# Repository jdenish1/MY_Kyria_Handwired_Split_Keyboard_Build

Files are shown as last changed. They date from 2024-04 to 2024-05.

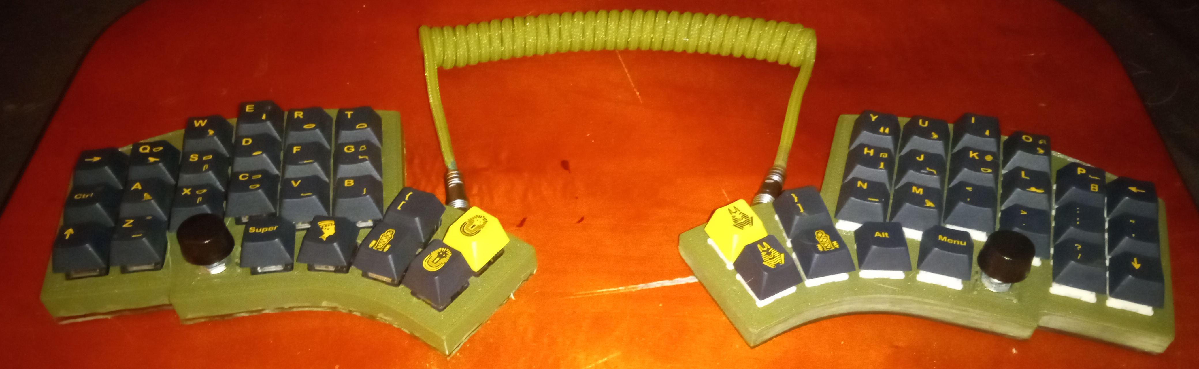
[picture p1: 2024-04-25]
Pics/2 - Completed Kyria Build 2.jpg

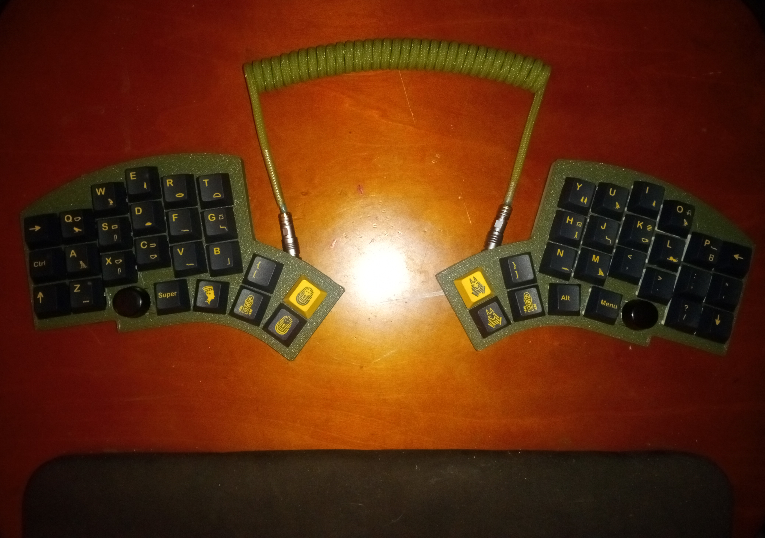
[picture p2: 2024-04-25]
Pics/1 - Completed Kyria Build 1.jpg

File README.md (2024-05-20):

<h1 align="center">Kyria_Handwired Split Keyboard</h1>

<div align="center">
<br />


<details open="open">
<summary>Table of Contents</summary>

- [About](#about)
  - [Bill of Materials](#built-with)
- [Getting Started](#getting-started)
  - [Prerequisites](#prerequisites)
  - [Usage](#usage)
    - [Cookiecutter template](#cookiecutter-template)
    - [Manual setup](#manual-setup)
    - [Variables reference](#variables-reference)
- [Roadmap](#roadmap)
- [Contributing](#contributing)
- [Support](#support)
- [License](#license)
- [Acknowledgements](#acknowledgements)

</details>

---

## About

<table>
<tr>
<td>

This is my rendition of a handwired split keyboard I did based on the Kyria by Thomas Baard ---> https://blog.splitkb.com/introducing-the-kyria/

This is my first split KB attempt and have been wanting to build a split for a while now. Ive done two other keyboard builds prior. Not only did I get inspiration from the original creator Thomas Baard but also from another github member MoltenZaz linked here ---> https://github.com/MoltenZaz/Handwired-Kyria. I dont know these guys personally but I got inspiration from their builds.

Try out the Keyswitch spacing with Baards printout here ----> https://docs.splitkb.com/hc/en-us/articles/360010627159-Can-I-try-the-Kyria-before-I-buy?ref=blog.splitkb.com

I added 2 EC11 rotary encoders, one per side, for the bottom left key on left side and bottom right key of right side which added a bit of complexity to the firmware build.

I also added WS2812 RGB Underglow to each side and ditched the 3d printed bottom plate for a handmade clear acrylic bottom plate.

Anyways, just made this public in case it helps anyone else out, in the spirit of the open source movement....

</td>
</tr>
</table>

### BOM
| # | Part | Type | Qty | Cost |
|:-:|:---:|:---|:----:|:---:|
| 1a| Keyswitches | Glorious Panda Tactile Switches - Unlubed |  x25 | $24.99 |
| 1b| Keyswitches | Cherry Red Tactile Switches - Unlubed |  x25 | $14.63 |
| 2 | Diodes | 1N4148 THT High Speed Switching Diodes | x100 | $ 2.30 |
| 3 | Controllers | Waveshare RP2040-Zero Microcontrollers | x2 | $ 4.08 |
| 4 | Encoders | EC11 20Pos 5VDC 7 Pin 360* Encoder w knobs| x2 | $ 4.03 |
| 5 | Connectors  | XS6 Mini Aviation Plug and Socket - 4Pin  | x2 | $ 8.16 |
| 6 | Heat Inserts| M2x6mm Heat Set Inserts - x30 needed | x50  | $ 4.68 |
| 7 | Screws | M2x6mm Countersunk - Black - x30 needed | x50  | $ 3.04 |
| 8 | Keycaps | GMK Pharoah Black & Gold Full Set | x1 | $24.99 |
| 9 | Keyboard Feet| Screw-In or Tape-On Your Choice | x10  | $ 4.99 |
| 10| 3D Printed Case | Printed on my Ratrig V Core 3 - On Hand| 4 pc | $ 0.00 |
| 11| Wire | I used Cat5e Solid Wire 26awg - On Hand | x1 | $ 1.00 |
| 12| USB Cable Wire| 24/4 shielded cable - On Hand ($0.45/ft |1-5ft | $ 1.50 |

## Getting Started

### Prerequisites

Download [QMK_MSYS](https://github.com/qmk/qmk_distro_msys/releases/download/1.9.0/QMK_MSYS.exe)
-or- If you use WSL - Windows Subsidiary for Linux - Download [QMK_WSL](https://github.com/qmk/qmk_distro_wsl/releases/download/0.4.2/QMK_WSL.exe)

Go to [qmk_firmware](https://github.com/qmk/qmk_firmware) and Fork your own repo 
[MY Repo](https://github.com/jdenish1/qmk_firmware)

Install QMK_WSL and run
```sh
qmk-admin
```
and complete quickstart wizard using your fork of qmk_firmware.

### Usage

Run
```sh
qmk compile -kb <keyboard/location> -km <keymap/location>
```




#### Manual setup

Please follow these steps for manual setup:

1. [Download the precompiled template](https://github.com/dec0dOS/amazing-github-template/releases/download/latest/template.zip)
2. Replace all the [variables](#variables-reference) to your desired values
3. Initialize the repo in the precompiled template folder

    `or`

    Move the necessary files from precompiled template folder to your existing project directory. Don't forget the `.github` directory that may be hidden by default in your operating system

## Roadmap

See the [open issues](https://github.com/dec0dOS/amazing-github-template/issues) for a list of proposed features (and known issues).

- [Top Feature Requests](https://github.com/dec0dOS/amazing-github-template/issues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) (Add your votes using the 👍 reaction)
- [Top Bugs](https://github.com/dec0dOS/amazing-github-template/issues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) (Add your votes using the 👍 reaction)
- [Newest Bugs](https://github.com/dec0dOS/amazing-github-template/issues?q=is%3Aopen+is%3Aissue+label%3Abug)

## Contributing

First off, thanks for taking the time to contribute! Contributions are what makes the open-source community such an amazing place to learn, inspire, and create. Any contributions you make will benefit everybody else and are **greatly appreciated**.

Please try to create bug reports that are:

- _Reproducible._ Include steps to reproduce the problem.
- _Specific._ Include as much detail as possible: which version, what environment, etc.
- _Unique._ Do not duplicate existing opened issues.
- _Scoped to a Single Bug._ One bug per report.

Please adhere to this project's [code of conduct](docs/CODE_OF_CONDUCT.md).

You can use [markdownlint-cli](https://github.com/igorshubovych/markdownlint-cli) to check for common markdown style inconsistency.

## Support

## Acknowledgements

Thanks for these awesome resources that were used during the development of the **Amazing GitHub template**:

- <https://github.com/cookiecutter/cookiecutter>
- <https://github.github.com/gfm/>
- <https://tom.preston-werner.com/2010/08/23/readme-driven-development.html>
- <https://changelog.com/posts/top-ten-reasons-why-i-wont-use-your-open-source-project>
- <https://thoughtbot.com/blog/how-to-write-a-great-readme>
- <https://www.makeareadme.com>

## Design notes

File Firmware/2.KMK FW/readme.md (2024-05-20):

Was having a hard time getting QMK to compile so I decided to try KMK FW instead. Before completely getting this working i started fresh with QMK and got it compiled on the default keymap. QMK FW files are more current and up to date so check that folder for current FW Files as well as the .uf2 and .hex files for flashing.

Thanks

Peace

-JRad

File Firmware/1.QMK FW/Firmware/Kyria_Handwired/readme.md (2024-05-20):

# kyria_handwired

kyria_handwired

*A short description of the keyboard/project*

* Keyboard Maintainer: [jdenish1](https://github.com/jdenish1)
* Hardware Supported: *The PCBs, controllers supported*
* Hardware Availability: *Links to where you can find this hardware*

Make example for this keyboard (after setting up your build environment):

    make kyria_handwired:default

Flashing example for this keyboard:

    make kyria_handwired:default:flash

See the [build environment setup](https://docs.qmk.fm/#/getting_started_build_tools) and the [make instructions](https://docs.qmk.fm/#/getting_started_make_guide) for more information. Brand new to QMK? Start with our [Complete Newbs Guide](https://docs.qmk.fm/#/newbs).

## Bootloader

Enter the bootloader in 3 ways:

* **Bootmagic reset**: Hold down the key at (0,0) in the matrix (usually the top left key or Escape) and plug in the keyboard
* **Physical reset button**: Briefly press the button on the back of the PCB - some may have pads you must short instead
* **Keycode in layout**: Press the key mapped to `QK_BOOT` if it is available

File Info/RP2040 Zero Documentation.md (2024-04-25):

# RP2040-Zero by Waveshare

<picture>
 <source media="(prefers-color-scheme: dark)" srcset="https://www.waveshare.com/img/devkit/RP2040-Zero/RP2040-Zero-details-1.jpg">
 <source media="(prefers-color-scheme: light)" srcset="https://www.waveshare.com/img/devkit/RP2040-Zero/RP2040-Zero-details-1.jpg">
 Waveshare RP2040-Zero Microcontroller Image
</picture>

## A Pico-like MCU board based on Raspberry Pi RP2040

### Board specifications

* RP2040 microcontroller chip designed by Raspberry Pi in the United Kingdom

* Dual-core Arm Cortex M0+ processor, flexible clock running up to 133 MHz

* 264KB of SRAM, and 2MB of on-board Flash memory

* USB-C connector, keeps it up to date, easier to use

* Castellated module allows soldering direct to carrier boards

* USB 1.1 with device and host support

* Low-power sleep and dormant modes

* Drag-and-drop programming using mass storage over USB

* 29 × multi-function GPIO pins (20× via edge pinout, others via solder points)

* 2 × SPI, 2 × I2C, 2 × UART, 4 × 12-bit ADC, 16 × controllable PWM channels

* Accurate clock and timer on-chip

* Temperature sensor

* Accelerated floating-point libraries on-chip

* 8 × Programmable I/O (PIO) state machines for custom peripheral support

#### Purchase

  [Waveshare](https://www.waveshare.com/rp2040-zero.htm)

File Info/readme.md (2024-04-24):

# Kyria's Default Keymap

KLE render of the default Kyria keymap with QWERTY as the base layer. Layers are shown in sublegends.

The default keymap contains 5 layers which allows it to include all keys found on an ANSI layout TKL keyboard plus media keys.
Hardware features of the Kyria such as OLEDs, rotary encoders and underglow are also supported.

The five different layers are the following:
1. Base layer (QWERTY, Colemak-DH or Dvorak)
2. Navigation layer
3. Symbols/Numbers layer
4. Function layer
5. Adjust layer

## Base layer(s)
```
Base Layer: -

,-------------------------------------------.                              ,-------------------------------------------.
|  Tab   |   -  |   -  |   -  |   -  |   -  |                              |   -  |   -  |   -  |   -  |   -  |  Bksp  |
|--------+------+------+------+------+------|                              |------+------+------+------+------+--------|
|Ctrl/Esc|   -  |   -  |   -  |   -  |   -  |                              |   -  |   -  |   -  |   -  |   -  |Ctrl/ - |
|--------+------+------+------+------+------+-------------.  ,-------------+------+------+------+------+------+--------|
| LShift |   -  |   -  |   -  |   -  |   -  | [ {  |CapsLk|  |F-Keys|  ] } |   -  |   -  |   -  |   -  |   -  | RShift |
`----------------------+------+------+------+------+------|  |------+------+------+------+------+----------------------'
                       |Adjust| LGUI | LAlt/| Space| Nav  |  | Sym  | Space| AltGr| RGUI | Menu |
                       |      |      | Enter|      |      |  |      |      |      |      |      |
                       `----------------------------------'  `----------------------------------'
```
Three different well-known keyboard layouts are provided to fill in the placeholder `-` keys: QWERTY, Colemak-DH, and Dvorak. The default layer can be changed at runtime, more info on that in the section on the [adjust layer](#adjust-layer).

For the rest of this write-up, the base layer will be assumed to be QWERTY and will be used as a reference to describe physical keys, e.g. “<kbd>B</kbd> key” vs, the much more verbose, “lower inner index key”.

```
Base Layer: QWERTY

,-------------------------------------------.                              ,-------------------------------------------.
|  Tab   |   Q  |   W  |   E  |   R  |   T  |                              |   Y  |   U  |   I  |   O  |   P  |  Bksp  |
|--------+------+------+------+------+------|                              |------+------+------+------+------+--------|
|Ctrl/Esc|   A  |   S  |   D  |   F  |   G  |                              |   H  |   J  |   K  |   L  | ;  : |Ctrl/' "|
|--------+------+------+------+------+------+-------------.  ,-------------+------+------+------+------+------+--------|
| LShift |   Z  |   X  |   C  |   V  |   B  | [ {  |CapsLk|  |F-keys|  ] } |   N  |   M  | ,  < | . >  | /  ? | RShift |
`----------------------+------+------+------+------+------|  |------+------+------+------+------+----------------------'
                       |Adjust| LGUI | LAlt/| Space| Nav  |  | Sym  | Space| AltGr| RGUI | Menu |
                       |      |      | Enter|      |      |  |      |      |      |      |      |
                       `----------------------------------'  `----------------------------------'
```

Aside from variations in the alpha cluster, the rest of the base keys remain the same and are designed to feel familiar.

Step-by-step animation of the transformation of an ortholinear TKL to a Kyria

<details>
After making transformations to the classic ANSI US QWERTY TKL 60% to arrive to the layout of the Kyria, as illustrated in the animation above, the result looks like this:

```
,-------------------------------------------.                              ,-------------------------------------------.
|  Tab   |   Q  |   W  |   E  |   R  |   T  |                              |   Y  |   U  |   I  |   O  |   P  |  Bksp  |
|--------+------+------+------+------+------|                              |------+------+------+------+------+--------|
| Cap Lk |   A  |   S  |   D  |   F  |   G  |                              |   H  |   J  |   K  |   L  | ;  : | '  "   |
|--------+------+------+------+------+------+-------------.  ,-------------+------+------+------+------+------+--------|
| LShift |   Z  |   X  |   C  |   V  |   B  |      |      |  |      |      |   N  |   M  | ,  < | . >  | /  ? | RShift |
`----------------------+------+------+------+------+------|  |------+------+------+------+------+----------------------'
                       | LCtrl| LGUI | LAlt | Space|      |  |      | Space| AltGr| RGUI | Menu |
                       |      |      |      |      |      |  |      |      |      |      |      |
                       `----------------------------------'  '----------------------------------'
```

First thing to notice is the presence of blank keys. To fill in the blank keys above the <kbd>Space</kbd> keys, we can take inspiration from other split keyboards featuring an extra inner index column on each half. A common mapping for those kind of keys are the bracket keys that got removed in the fourth step of the animated transformation. The thumb keys besides <kbd>Space</kbd>s is prime real estate for dedicated layer-switching keys. It doesn't matter on which side is assigned the sym-layer-switch key but it helps to keep the nav-layer-switch on the left in order to keep the arrow keys on the right side like on a classic keyboard, so we'll put nav on the left and sym on the right. We'll address the remaining blank thumb keys later.

The base layer is starting to form but there remains some flaws. One glaring issue is the position of Control. Control is a very commonly used function but the key on which it sits right now is way too tucked in under the hand to be able to press it comfortably with either the thumb or the pinky from resting position. In fact, installing a rotary encoder there is a common move among Kyria users and I guarantee you that activating Control by holding down a rotary encoder does not spark joy. Instead, let's employ a popular trick that involves remapping the current Caps Lock key, which is positioned at a comfortable position on the keyboard, to Control. 

We can go further though; a variant of this trick makes the Control key produce Escape when tapped. This is called a “modtap”. There is no use to tapping Control by itself without chording it with another key and there is no use to holding down the Esc key so why not combine the two into a single key?

All of this leaves us with three blank keys.

```
,-------------------------------------------.                              ,-------------------------------------------.
|  Tab   |   Q  |   W  |   E  |   R  |   T  |                              |   Y  |   U  |   I  |   O  |   P  |  Bksp  |
|--------+------+------+------+------+------|                              |------+------+------+------+------+--------|
|Ctrl/Esc|   A  |   S  |   D  |   F  |   G  |                              |   H  |   J  |   K  |   L  | ;  : | '  "   |
|--------+------+------+------+------+------+-------------.  ,-------------+------+------+------+------+------+--------|
| LShift |   Z  |   X  |   C  |   V  |   B  | [ {  |      |  |      |  ] } |   N  |   M  | ,  < | . >  | /  ? | RShift |
`--------+-------------+--------------------+------+------|  |------+------+--------------------+------+---------------'
                       |      | LGUI | LAlt | Space| Nav  |  | Sym  | Space| AltGr| RGUI | Menu |
                       |      |      |      |      |      |  |      |      |      |      |      |
                       `----------------------------------'  '----------------------------------'
```

These keys are not easily reachable while touch typing (that is, not reachable without picking up your hand) and should thus be associated with functions that you are not likely to be typed within a stream of text. The idea is that if you have to pick up your hand to hit a key, you want it to be at a time when you are likely to be pausing your interaction with the machine, rather than in the midst of a flurry of typing.  They're thus well suited for accessing the adjust layer and the function layer. We can also toss in Caps Lock even though it is an editing-type function that gets used within a stream of text because shouting in ALL-CAPS should be a deliberate action.

```
,-------------------------------------------.                              ,-------------------------------------------.
|  Tab   |   Q  |   W  |   E  |   R  |   T  |                              |   Y  |   U  |   I  |   O  |   P  |  Bksp  |
|--------+------+------+------+------+------|                              |------+------+------+------+------+--------|
|Ctrl/Esc|   A  |   S  |   D  |   F  |   G  |                              |   H  |   J  |   K  |   L  | ;  : | '  "   |
|--------+------+------+------+------+------+-------------.  ,-------------+------+------+------+------+------+--------|
| LShift |   Z  |   X  |   C  |   V  |   B  | [ {  |CapsLk|  |F-keys|  ] } |   N  |   M  | ,  < | . >  | /  ? | RShift |
`----------------------+------+------+------+------+------|  |------+------+------+------+------+----------------------'
                       |Adjust| LGUI | LAlt | Space| Nav  |  | Sym  | Space| AltGr| RGUI | Menu |
                       |      |      |      |      |      |  |      |      |      |      |      |
                       `----------------------------------'  `----------------------------------'
```

The next glaring issue is the absence of an Enter key on the current base layer this far. Enter is a very frequently used key so it deserves to be placed at a good spot in the keymap. The best way to insert it in the keymap with minimal changes to the current layout is to use modtaps. A tempting solution is to turn the <kbd>RShift</kbd> key into a <kbd>RShift/Enter</kbd> modtap but that can result in chat messages sent too frustratingly early when you're not used to it. Using GUI is also sub-optimal because tapping the GUI modifier actually has a use as opposed to taps of the Control or the Shift key. Pressing and releasing the GUI key by itself opens the App menu in many desktop environments. The natural choice is thus <kbd>LAlt/Enter</kbd>. That way, Enter is 1u away from resting thumb position and is unlikely to get accidentally activated because Alt is very rarely used in the midst of prose.

Finally, we're one Quality-Of-Life update away from the actual base layer. <kbd>Ctrl/' "</kbd> not only preserves symmetry in the keymap with <kbd>Ctrl/Esc</kbd> but also helps balance the load between your pinkies and invites you to use both hands instead of contortions. Perhaps more importantly, it also frees you from the necessity of picking up your hand, breaking touch typing position and pressing a pinky key with your ring finger in order to execute Ctrl+A or Ctrl+Z. That becomes even more important on a board with such an aggressive pinky columnar stagger like the Kyria.

```
,-------------------------------------------.                              ,-------------------------------------------.
|  Tab   |   Q  |   W  |   E  |   R  |   T  |                              |   Y  |   U  |   I  |   O  |   P  |  Bksp  |
|--------+------+------+------+------+------|                              |------+------+------+------+------+--------|
|Ctrl/Esc|   A  |   S  |   D  |   F  |   G  |                              |   H  |   J  |   K  |   L  | ;  : |Ctrl/' "|
|--------+------+------+------+------+------+-------------.  ,-------------+------+------+------+------+------+--------|
| LShift |   Z  |   X  |   C  |   V  |   B  | [ {  |CapsLk|  |F-keys|  ] } |   N  |   M  | ,  < | . >  | /  ? | RShift |
`----------------------+------+------+------+------+------|  |------+------+------+------+------+----------------------'
                       |Adjust| LGUI | LAlt/| Space| Nav  |  | Sym  | Space| AltGr| RGUI | Menu |
                       |      |      | Enter|      |      |  |      |      |      |      |      |
                       `----------------------------------'  `----------------------------------'
```

</details>

## Navigation layer

```
Nav Layer: Media, navigation
                                                                                                                         
,-------------------------------------------.                              ,-------------------------------------------.
|        |      |      |      |      |      |                              | PgUp | Home |   ↑  | End  | VolUp| Delete |
|--------+------+------+------+------+------|                              |------+------+------+------+------+--------|
|        |  GUI |  Alt | Ctrl | Shift|      |                              | PgDn |  ←   |   ↓  |   →  | VolDn| Insert |
|--------+------+------+------+------+------+-------------.  ,-------------+------+------+------+------+------+--------|
|        |      |      |      |      |      |      |ScLck |  |      |      | Pause|M Prev|M Play|M Next|VolMut| PrtSc  |
`----------------------+------+------+------+------+------|  |------+------+------+------+------+----------------------'
                       |      |      |      |      |      |  |      |      |      |      |      |
                       |      |      |      |      |      |  |      |      |      |      |      |
                       `----------------------------------'  `----------------------------------'
```

This is where you'll find all the keys that are generally between the main block of a classic keyboard and the numpad in addition to media controls and modifiers on easy access on the home row for fast and comfortable chording with navigation keys.

Useful mnemonics:
- “GACS” to remember the order of the modifiers on the left-hand home row
- <kbd>Scroll Lock</kbd> is on the same key as <kbd>Caps Lock</kbd> because they're both locks
- <kbd>Delete</kbd> is on the same key as <kbd>Backspace</kbd> because they both erase characters
- <kbd>Home</kbd> is the leftmost position on the current line so it is above <kbd>←</kbd>. Same logic applies for <kbd>End</kbd>.
- <kbd>Media Previous</kbd> = ⏮, <kbd>Media Next</kbd> = ⏭
- <kbd>Page Up</kbd>, <kbd>Page Down</kbd> and <kbd>Volume Up</kbd>, <kbd>Volume Down</kbd> are positioned like the main <kbd>Up</kbd> and <kbd>Down</kbd> keys.

## Sym layer
```
Sym Layer: Numbers, symbols
                                                                                                                         
,-------------------------------------------.                              ,-------------------------------------------.
|    `   |  1   |  2   |  3   |  4   |  5   |                              |   6  |  7   |  8   |  9   |  0   |   =    |
|--------+------+------+------+------+------|                              |------+------+------+------+------+--------|
|    ~   |  !   |  @   |  #   |  $   |  %   |                              |   ^  |  &   |  *   |  (   |  )   |   +    |
|--------+------+------+------+------+------+-------------.  ,-------------+------+------+------+------+------+--------|
|    |   |   \  |  :   |  ;   |  -   |  [   |  {   |      |  |      |   }  |   ]  |  _   |  ,   |  .   |  /   |   ?    |
`----------------------+------+------+------+------+------|  |------+------+------+------+------+----------------------'
                       |      |      |      |      |      |  |      |      |      |      |      |
                       |      |      |      |      |      |  |      |      |      |      |      |
                       `----------------------------------'  `----------------------------------'
```
The top row is the unshifted num row, the home row of the layer is the shifted num row and the bottom row contains the hyphen `-` and the underscore `_` on the best lower row spot because of how frequent they are as well as redundant symbols that are already present on the base layer but are reproduced here to avoid juggling back and forth between base, shift, and sym when typing a string of symbols.

The layout of the first two rows needs no introduction, you're already used to them but it's worth looking into the structure of the bottom row.

The two halves are mirrored in a sense. On the right, you can find <kbd>,</kbd> <kbd>.</kbd> <kbd>/</kbd> at their usual spots with the addition of <kbd>Shift</kbd>+<kbd>/</kbd>=<kbd>?</kbd> to the right of the <kbd>/</kbd> key to remove the need to press simultaneously <kbd>Sym</kbd> and a <kbd>Shift</kbd> key to access `?`. 

Now, if you look at the left side, you'll notice that the mirror of <kbd>,</kbd> is <kbd>;</kbd>, the mirror of <kbd>.</kbd> is <kbd>:</kbd> and the mirror of <kbd>/</kbd> is <kbd>\\</kbd>. The same logic used for <kbd>Shift</kbd>+<kbd>/</kbd>=<kbd>?</kbd> also applies to <kbd>Shift</kbd>+<kbd>\\</kbd>=<kbd>|</kbd>.

In case you wish to combine <kbd>Shift</kbd> with a symbol key anyways, you can hold down <kbd>Shift</kbd> on the base layer with your pinky, activate <kbd>Sym</kbd> with your right thumb and while still holding down the <kbd>Shift</kbd> key, tap your desired symbol key. Same thing if you need <kbd>Ctrl</kbd>+<kbd>Digit</kbd>.

## Function layer
```
Function Layer: Function keys
                                                                                                                         
,-------------------------------------------.                              ,-------------------------------------------.
|        |  F9  | F10  | F11  | F12  |      |                              |      |      |      |      |      |        |
|--------+------+------+------+------+------|                              |------+------+------+------+------+--------|
|        |  F5  |  F6  |  F7  |  F8  |      |                              |      | Shift| Ctrl |  Alt |  GUI |        |
|--------+------+------+------+------+------+-------------.  ,-------------+------+------+------+------+------+--------|
|        |  F1  |  F2  |  F3  |  F4  |      |      |      |  |      |      |      |      |      |      |      |        |
`----------------------+------+------+------+------+------|  |------+------+------+------+------+----------------------'
                       |      |      |      |      |      |  |      |      |      |      |      |
                       |      |      |      |      |      |  |      |      |      |      |      |
                       `----------------------------------'  `----------------------------------'
```
In a similar fashion to the nav layer, pressing down `FKEYS` with the right thumb enables a numpad of function keys on the opposite hand and modifiers on the right-hand home row. Once again, mirror symmetry is leveraged in this keymap for the order of the right-hand modifiers.

The <kbd>Alt</kbd> modifier, despite being situated on the right half of the keyboard is *not* `KC_RALT`, it is `KC_LALT`. `KC_RALT` is actually the <kbd>AltGr</kbd> key which generally acts very differently to the left <kbd>Alt</kbd> key. Keyboard shortcuts involving <kbd>AltGr</kbd>+<kbd>F#</kbd> are rare and infrequent as opposed to the much more common <kbd>Alt</kbd>+<kbd>F#</kbd> shortcuts. Consequently, `KC_LALT` was chosen for the function layer.

Since there are more than 10 function keys, the cluster of F-keys does not follow the usual 3×3+1 numpad arrangement.

## Adjust layer
```
Adjust Layer: Default layer settings, RGB
                                                                                                                         
,-------------------------------------------.                              ,-------------------------------------------.
|        |      |      |QWERTY|      |      |                              |      |      |      |      |      |        |
|--------+------+------+------+------+------|                              |------+------+------+------+------+--------|
|        |      |      |Dvorak|      |      |                              | TOG  | SAI  | HUI  | VAI  | MOD  |        |
|--------+------+------+------+------+------+-------------.  ,-------------+------+------+------+------+------+--------|
|        |      |      |Colmak|      |      |      |      |  |      |      |      | SAD  | HUD  | VAD  | RMOD |        |
`----------------------+------+------+------+------+------|  |------+------+------+------+------+----------------------'
                       |      |      |      |      |      |  |      |      |      |      |      |
                       |      |      |      |      |      |  |      |      |      |      |      |
                       `----------------------------------'  `----------------------------------'
```

Default layer settings on the left and various RGB underglow controls on the right.

The default layer settings are lined up on the middle finger column because the home middle finger key is <kbd>D</kbd> on QWERTY (like the “D” in “Dvorak”) and the lower middle finger key is <kbd>C</kbd> on QWERTY (like the “C” in “Colemak”). I can hear you say that “QWERTY” doesn't start with “E” but Dvorak and Colemak were already aligned in a column so the QWERTY may as well join the formation.

NOTE: The default layer settings set by those keys are *NOT* stored in EEPROM and thus do not persist through boots. If you wish to change the default layer in a non-volatile manner, either change the order of the layers in the firmware, for example like so if you want to set Dvorak as the new default:
```c
enum layers {
    _DVORAK = 0,
    _QWERTY,
    _COLEMAK_DH,
    _NAV,
    _SYM,
    _FUNCTION,
    _ADJUST
};
```
or re-define the `QWERTY`, `COLEMAK` and `DVORAK` keys to point to custom keycodes starting on `SAFE_RANGE` and calling the `set_single_persistent_default_layer` function inside of `process_record_user`.

## Hardware Features

### Rotary Encoder
The left rotary encoder is programmed to control the volume whereas the right encoder sends <kbd>PgUp</kbd> or <kbd>PgDn</kbd> on every turn.

### OLEDs
The OLEDs display the current layer at the top of the active layers stack, the Kyria logo and lock status (caps lock, num lock, scroll lock).

### Underglow
The underglow LEDs should be red.

## Going further…

This default keymap can be used as is, unchanged, as a daily driver for your Kyria but you're invited to treat your keymap like a bonsai. At the beginning, it's just like the default keymap but from time to time, you can tweak it a little. Cut a little key here, let another combo grow there. Slowly but surely it will be a unique keymap that will fit you like a glove.

Check out the #keymap-ideas channel on the official SplitKB Discord server for inspiration.

----------------------------------------------------------------------------------------------

Make example for this keyboard (after setting up your build environment):

    make kyria_handwired:default

Flashing example for this keyboard:

    make kyria_handwired:default:flash

See the [build environment setup](https://docs.qmk.fm/#/getting_started_build_tools) and the [make instructions](https://docs.qmk.fm/#/getting_started_make_guide) for more information. Brand new to QMK? Start with our [Complete Newbs Guide](https://docs.qmk.fm/#/newbs).

## Bootloader

Enter the bootloader in 3 ways:

* **Bootmagic reset**: Hold down the key at (0,0) in the matrix (usually the top left key or Escape) and plug in the keyboard
* **Physical reset button**: Briefly press the button on the back of the PCB - some may have pads you must short instead
* **Keycode in layout**: Press the key mapped to `QK_BOOT` if it is available

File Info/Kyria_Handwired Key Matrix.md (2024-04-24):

LEFT SIDE

Top Row			0,0 ; 0,1 ; 0,2 ; 0,3 ; 0,4 ; 0,5

2nd Row			1,0 ; 1,1 ; 1,2 ; 1,3 ; 1,4 ; 1,5

3rd Row			2,0 ; 2,1 ; 2,2 ; 2,3 ; 2,4 ; 2,5 ; 2,6 ; 2,7

Bot Row					  3,3 ; 3,4 ; 3,5 ; 3,6 ; 3,7

RIGHT SIDE

Top Row				     4,11 ; 4,12 ; 4,13 ; 4,14 ; 4,15 ; 4,16

2nd Row				     5,11 ; 5,12 ; 5,13 ; 5,14 ; 5,15 ; 5,16

3rd Row			6,9 ; 6,10 ; 6,11 ; 6,12 ; 6,13 ; 6,14 ; 6,15 ; 6,16

Bot Row			7,9 ; 7,10 ; 7,11 ; 7,12 ; 7,13 

		   Rows: 8

		Columns: 17

	Diode Direction: COL2ROW

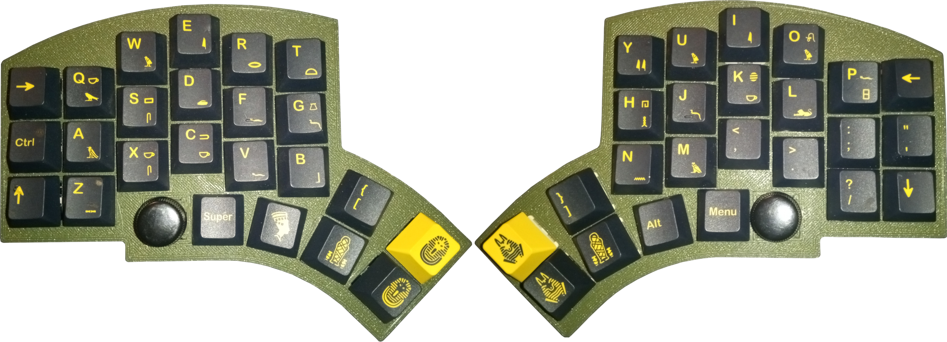
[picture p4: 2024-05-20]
Pics/Whole Keyboard Cropped.png

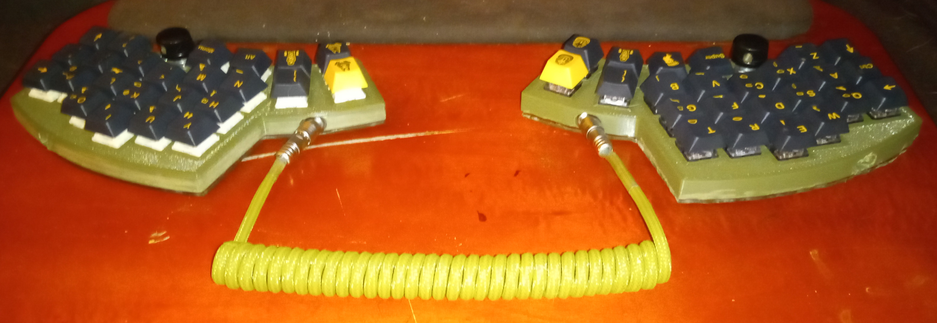
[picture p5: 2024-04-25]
Pics/12 - XS6 Cable Closeup 3.jpg

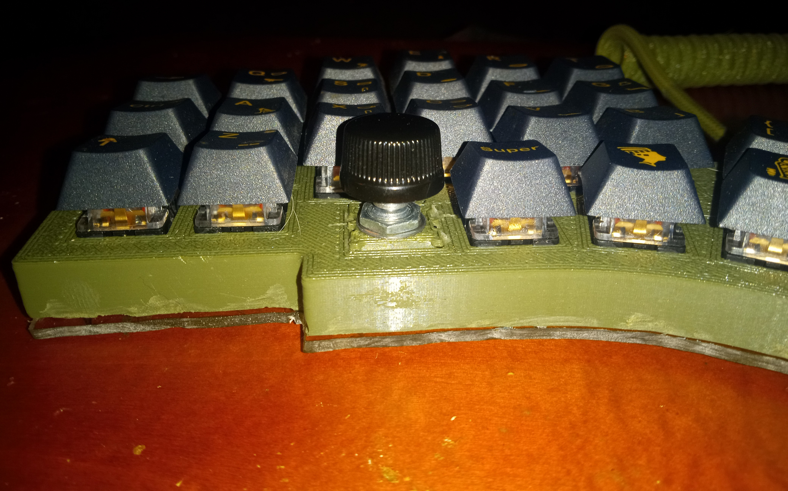
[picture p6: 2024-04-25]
Pics/8 - Left Side 3.jpg

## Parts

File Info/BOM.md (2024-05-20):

# Kyria_Handwired Keyboard B.O.M.

## BOM
| # | Part | Type | Qty | Cost |
|:-:|:---:|:---|:----:|:---:|
| 1a| Keyswitches | Glorious Panda Tactile Switches - Unlubed |  x25 | $24.99 |
| 1b| Keyswitches | Cherry Red Tactile Switches - Unlubed |  x25 | $14.63 |
| 2 | Diodes | 1N4148 THT High Speed Switching Diodes | x100 | $ 2.30 |
| 3 | Controllers | Waveshare RP2040-Zero Microcontrollers | x2 | $ 4.08 |
| 4 | Encoders | EC11 20Pos 5VDC 7 Pin 360* Encoder w knobs| x2 | $ 4.03 |
| 5 | Connectors  | XS6 Mini Aviation Plug and Socket - 4Pin  | x2 | $ 8.16 |
| 6 | Heat Inserts| M2x6mm Heat Set Inserts - x30 needed | x50  | $ 4.68 |
| 7 | Screws | M2x6mm Countersunk - Black - x30 needed | x50  | $ 3.04 |
| 8 | Keycaps | GMK Pharoah Black & Gold Full Set | x1 | $24.99 |
| 9 | Keyboard Feet| Screw-In or Tape-On Your Choice | x10  | $ 4.99 |
| 10| 3D Printed Case | Printed on my Ratrig V Core 3 - On Hand| 4 pc | $ 0.00 |
| 11| Wire | I used Cat5e Solid Wire 26awg - On Hand | x1 | $ 1.00 |
| 12| USB Cable Wire| 24/4 shielded cable - On Hand ($0.45/ft |1-5ft | $ 1.50 |

### Datasheets
<ol>
<li> - & - </li>  
<li>  - </li>
<li>  - https://core-electronics.com.au/rp2040-zero-a-pico-like-mcu-board-based-on-raspberry-pi-mcu-rp2040-mini-ver-1.html </li>
<li>  - https://www.farnell.com/datasheets/1837001.pdf</li>
<li>  - https://www.aliexpress.com/item/1005004089293971.html</li>
<li>  - </li>
<li>  - </li>
<li>  - </li>
<li>  - </li>
<li>  - </li>
<li>  - </li>
<li>  - </li>

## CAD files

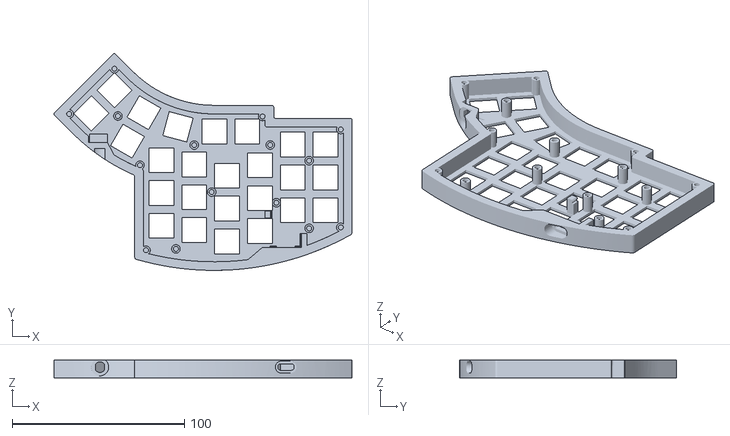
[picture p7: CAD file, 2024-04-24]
3D Printed Case STLs/Case Top - Right.stl
172.9 x 125.7 x 10.4

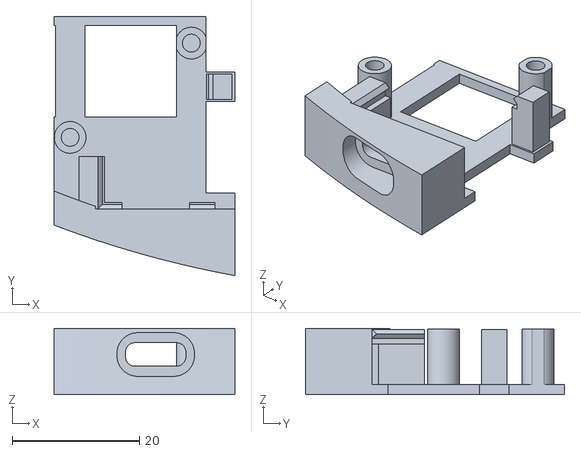
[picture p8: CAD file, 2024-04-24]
3D Printed Case STLs/Test Files/Tolerance Test - Microcontroller.stl
28.5 x 40.8 x 10.4

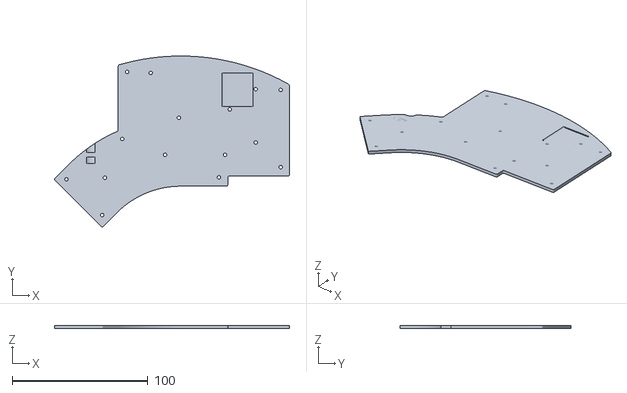
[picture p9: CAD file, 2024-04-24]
3D Printed Case STLs/Case Bottom - Right.stl
172.9 x 125.8 x 2.30

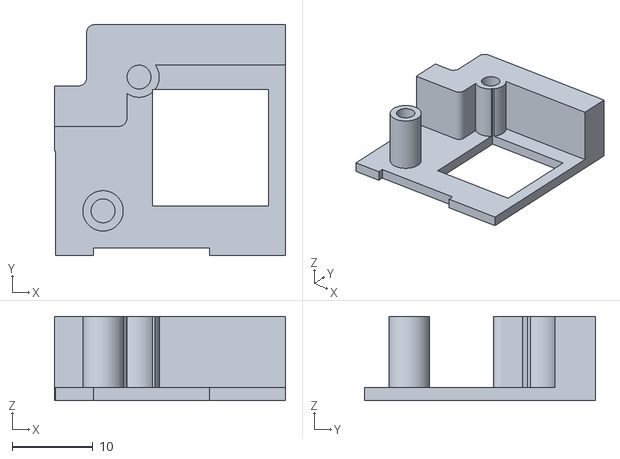
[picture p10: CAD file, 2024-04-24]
3D Printed Case STLs/Test Files/Tolerance Tests - Standoffs.stl
28.6 x 28.5 x 10.4

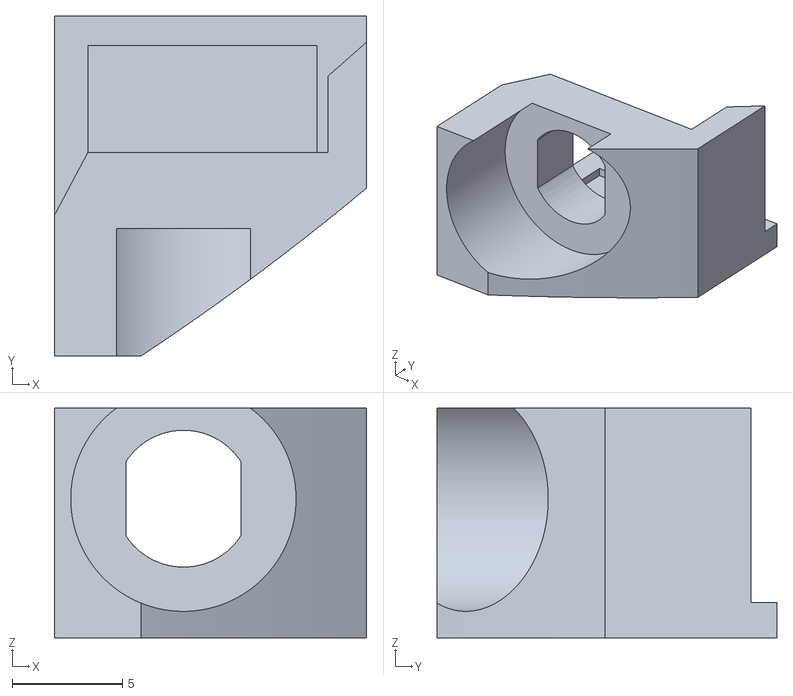
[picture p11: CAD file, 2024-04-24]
3D Printed Case STLs/Test Files/Tolerance Test - XS6 Mini 4 Pin.stl
14.1 x 15.4 x 10.4

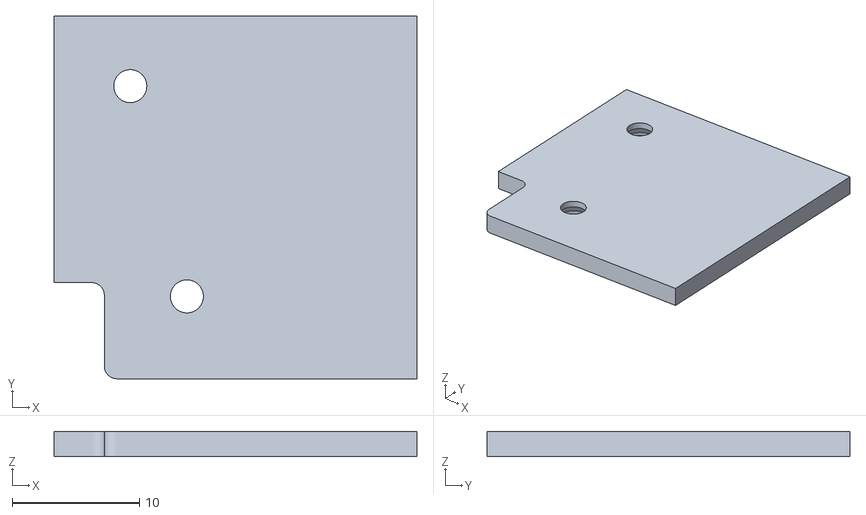
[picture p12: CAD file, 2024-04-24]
3D Printed Case STLs/Test Files/Tolerance Test - Standoff Bottom.stl
28.6 x 28.5 x 1.98

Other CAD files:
3D Printed Case STLs/Case Bottom - Left.stl

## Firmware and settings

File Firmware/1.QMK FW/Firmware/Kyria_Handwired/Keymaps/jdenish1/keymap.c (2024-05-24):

// Copyright 2023 QMK
// SPDX-License-Identifier: GPL-2.0-or-later

#include QMK_KEYBOARD_H

enum layers {
    _QWERTY = 0,
    _NUM = 1,
    _NAV = 2,
    _FKEY = 3,
};

// Aliases for readability
#define QWER     DF(_QWERTY)
#define NUM      TG(_NUM)
#define NAV      TG(_NAV)
#define FKEY     TG(_FKEY)

#define CTL_ESC  MT(MOD_LCTL, KC_ESC)
#define CTL_QUOT MT(MOD_RCTL, KC_QUOTE)
#define CTL_MINS MT(MOD_RCTL, KC_MINUS)
#define ALT_ENT  MT(MOD_LALT, KC_ENT)


// Note: LAlt/Enter (ALT_ENT) is not the same thing as the keyboard shortcut Alt+Enter.
// The notation `mod/tap` denotes a key that activates the modifier `mod` when held down, and
// produces the key `tap` when tapped (i.e. pressed and released).

const uint16_t PROGMEM keymaps[][MATRIX_ROWS][MATRIX_COLS] = {

/*
 * Base Layer: QWERTY
 *
 * ,-------------------------------------------.                              ,-------------------------------------------.
 * |  Tab   |   Q  |   W  |   E  |   R  |   T  |                              |   Y  |   U  |   I  |   O  |   P  |  Bksp  |
 * |--------+------+------+------+------+------|                              |------+------+------+------+------+--------|
 * |Ctrl/Esc|   A  |   S  |   D  |   F  |   G  |                              |   H  |   J  |   K  |   L  | ;  : |Ctrl/' "|
 * |--------+------+------+------+------+------+-------------.  ,-------------+------+------+------+------+------+--------|
 * | LShift |   Z  |   X  |   C  |   V  |   B  | [ {  |CapsLk|  | Num  |  ] } |   N  |   M  | ,  < | . >  | /  ? | RShift |
 * `----------------------+------+------+------+------+------|  |------+------+------+------+------+----------------------'
 *                        |Adjust| LGUI | LAlt/| Space| Nav  |  |F-keys| Space| AltGr| RGUI | Mute |
 *                        |(Enco)|      | Enter|      |      |  |      |      |      |      |(Enco)|
 *                        `----------------------------------'  `----------------------------------'
 */
    [QWER] = LAYOUT_split_3x6_5(
      KC_TAB  , KC_Q ,  KC_W   ,  KC_E  ,   KC_R ,  KC_T  ,                                        KC_Y   , KC_U   , KC_I   , KC_O  , KC_P   , KC_BSPC ,
      CTL_ESC , KC_A ,  KC_S   ,  KC_D  ,   KC_F ,  KC_G  ,                                        KC_H   , KC_J   , KC_K   , KC_L  , KC_SCLN, CTL_QUOT,
      KC_LSFT , KC_Z ,  KC_X   ,  KC_C  ,   KC_V ,  KC_B  , KC_LBRC, KC_CAPS,       NUM , KC_RBRC, KC_N   , KC_M   , KC_COMM, KC_DOT, KC_SLSH, KC_RSFT ,
                                 KC_APP , KC_LGUI, ALT_ENT, KC_SPC ,   NAV  ,       FKEY, KC_SPC , KC_RALT, KC_RGUI, KC_MUTE
    ),

/*
 * Num Layer: Numbers and symbols
 *
 * ,-------------------------------------------.                              ,-------------------------------------------.
 * |    `   |  1   |  2   |  3   |  4   |  5   |                              |   6  |  7   |  8   |  9   |  0   |   =    |
 * |--------+------+------+------+------+------|                              |------+------+------+------+------+--------|
 * |    ~   |  !   |  @   |  #   |  $   |  %   |                              |   ^  |  &   |  *   |  (   |  )   |   +    |
 * |--------+------+------+------+------+------+-------------.  ,-------------+------+------+------+------+------+--------|
 * |    |   |   \  |  :   |  ;   |  -   |  [   |  {   | QWER |  | Num  |   }  |   ]  |  _   |  ,   |  .   |  /   |   ?    |
 * `----------------------+------+------+------+------+------|  |------+------+------+------+------+----------------------'
 *                        |Adjust| LGUI | LAlt/| Space| Nav  |  |F-keys| Space| AltGr| RGUI | Mute |
 *                        |(Enco)|      | Enter|      |      |  |      |      |      |      |(Enco)|
 *                        `----------------------------------'  `----------------------------------'
 */
    [NUM] = LAYOUT_split_3x6_5(
      KC_GRV , KC_1   , KC_2   , KC_3   , KC_4   , KC_5   ,                                      KC_6   , KC_7   , KC_8   , KC_9   , KC_0   , KC_EQL ,
      KC_TILD, KC_EXLM, KC_AT  , KC_HASH, KC_DLR , KC_PERC,                                      KC_CIRC, KC_AMPR, KC_ASTR, KC_LPRN, KC_RPRN, KC_PLUS,
      KC_PIPE, KC_BSLS, KC_COLN, KC_SCLN, KC_MINS, KC_LBRC, KC_LCBR,  QWER,    KC_TRNS, KC_RCBR, KC_RBRC, KC_UNDS, KC_COMM, KC_DOT , KC_SLSH, KC_QUES,
                                 KC_APP , KC_LGUI, ALT_ENT, KC_SPC ,  NAV ,     FKEY  , KC_SPC , KC_RALT, KC_RGUI, KC_MUTE
    ),

/*
 * Nav Layer: Media, navigation
 *
 * ,-------------------------------------------------.                              ,-------------------------------------------.
 * |        |  GUI  |  Alt   | Ctrl  | Shift |       |                              | PgUp | Home |   ↑  | End  | VolUp| Delete |
 * |--------+-------+--------+-------+-------+-------|                              |------+------+------+------+------+--------|
 * |        |RGB_SPI|RGB_MOD |RGB_VAI|RGB_HUI|RGB_SAI|                              | PgDn |  ←   |   ↓  |   →  | VolDn| Insert |
 * |--------+-------+--------+-------+-------+-------+-------------.  ,-------------+------+------+------+------+------+--------|
 * |        |RGB_SPD|RGB_RMOD|RGB_VAD|RGB_HUD|RGB_SAD|      | QWER |  | NUM  |      | Pause|M Prev|M Play|M Next|VolMut| PrtSc  |
 * `-------------------------+-------+-------+-------+------+------|  |------+------+------+------+------+----------------------'
 *                           | Adjust| LGUI  | LAlt/ | Space|      |  | FKEYS| Space| AltGr| RGUI | Mute |
 *                           | (Enco)|       | Enter |      |      |  |      |      |      |      |(Enco)|
 *                           `-------------------------------------'  `----------------------------------'
 */
    [NAV] = LAYOUT_split_3x6_5(
      KC_TRNS, KC_LGUI, KC_LCTL , KC_LSFT, KC_TRNS, KC_TRNS,                                    KC_PGUP, KC_HOME, KC_UP  , KC_END , KC_VOLU, KC_DEL,
      KC_TRNS, RGB_SPI, RGB_MOD , RGB_VAI, RGB_HUI, RGB_SAI,                                    KC_PGDN, KC_LEFT, KC_DOWN, KC_RGHT, KC_VOLD, KC_INS,
      KC_TRNS, RGB_SPD, RGB_RMOD, RGB_VAD, RGB_HUD, RGB_SAD, KC_TRNS,  QWER  ,    NUM, KC_TRNS, KC_PAUS, KC_MPRV, KC_MPLY, KC_MNXT, KC_MUTE, KC_PSCR,
                                  KC_APP , KC_LGUI, ALT_ENT, KC_SPC , KC_TRNS,   FKEY, KC_SPC , KC_RALT, KC_RGUI, KC_MUTE
    ),
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

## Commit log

2024-04-24 new file: Info/BOM.md new file: Info/readme.md new file: QMK FW Files/Encoders - docs.qmk.fm.pdf new file: QMK FW Files/Info.json Format Reference - docs.qmk.fm.pdf new file: QMK FW Files/Keyboard/Ke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
2024-04-24 new file: 3D Printed Case STLs/Test Files/microcontroller_tolerance_test.stl new file: 3D Printed Case STLs/Test Files/standoff_bottom_tolerance_test.stl new file: 3D Printed Case STLs/Test Files/sta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
    [case_bottom_left.stl, microcontroller_tolerance_test.stl, standoff_bottom_tolerance_test.stl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]
2024-04-24 renamed: 3D Printed Case STLs/case_bottom_left.stl -> 3D Printed Case STLs/Case Bottom - Left.stl new file: 3D Printed Case STLs/Case Bottom - Right.stl renamed: 3D Printed Case STLs/case_top_left.st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
    [Case Bottom - Left.stl, Case Bottom - Right.stl, Case Top - Right.stl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]
2024-04-25 Changes to be committed: new file: Pics/1 - Completed Kyria Build 1.jpg new file: Pics/10 - XS6 Cable Closeup 1.jpg new file: Pics/11 - XS6 Cable Closeup 2.jpg new file: Pics/12 - XS6 Cable Closeup 3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
2024-05-09 new file: Firmware/KMK FW/KMK Setup Docs/Combos.pdf new file: Firmware/KMK FW/KMK Setup Docs/Config_and_Keymap.pdf new file: Firmware/KMK FW/KMK Setup Docs/Extension_StatusLED.pdf new file: Firmware/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
2024-05-09 new file: Firmware/KMK FW/KMK Setup Docs/1 - kmkfw.io-Getting Started.pdf new file: Firmware/KMK FW/KMK Setup Docs/10 - kmkfw.io-HoldTap Keycodes.pdf new file: Firmware/KMK FW/KMK Setup Docs/11 - kmk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
2024-05-10 deleted: QMK FW Files/Config Files/QMK-CONFIGURATOR - splitkb_kyria_rev3_layout_split_3x6_5_mine.json deleted: QMK FW Files/Config Files/README.md deleted: "QMK FW Files/Config Files/Serialized Data 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
